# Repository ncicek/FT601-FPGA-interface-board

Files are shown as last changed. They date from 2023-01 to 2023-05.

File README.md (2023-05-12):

# FTDI FT601 breakout board

A PCB for interfacing FT601 with Lattice MachXO3 Starter Board.
Examples of C driver and Python driver can be found in driver folder.
Verilog and cocotb sims are in fpga folder.

# PCB:
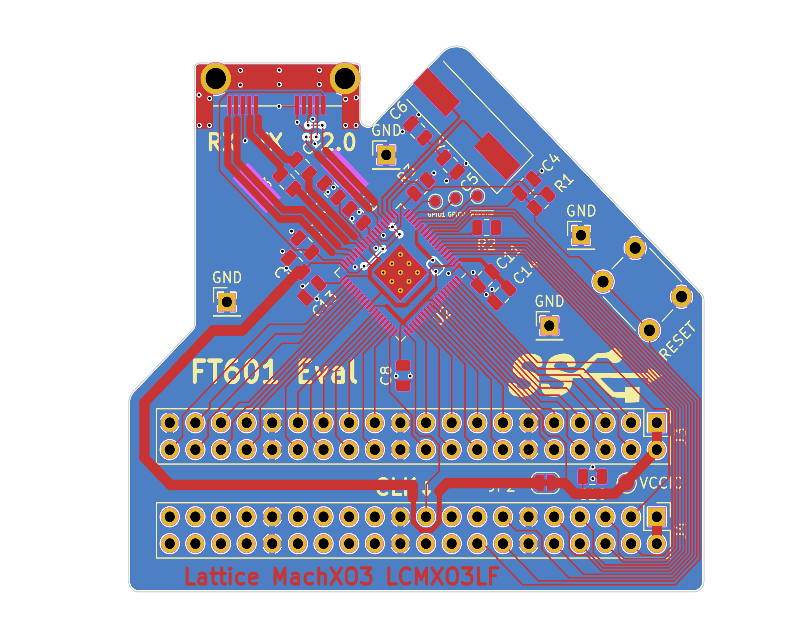
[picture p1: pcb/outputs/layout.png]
Photo of the ft601 layout

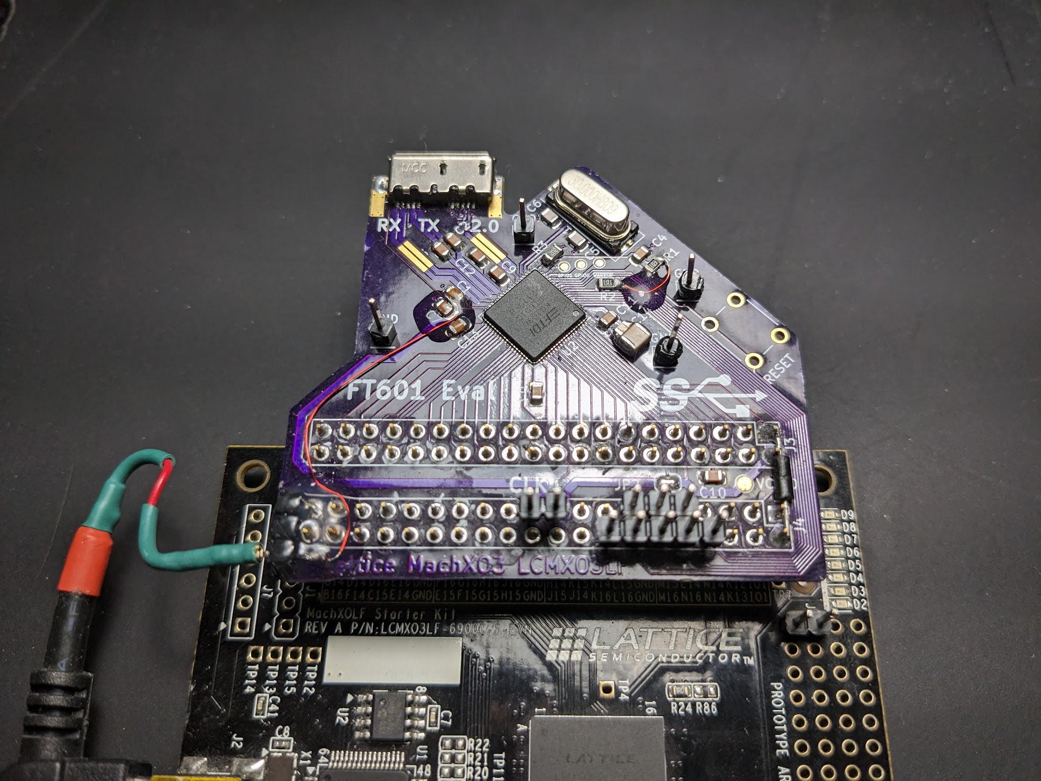
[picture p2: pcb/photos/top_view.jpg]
Photo of the ft601 board


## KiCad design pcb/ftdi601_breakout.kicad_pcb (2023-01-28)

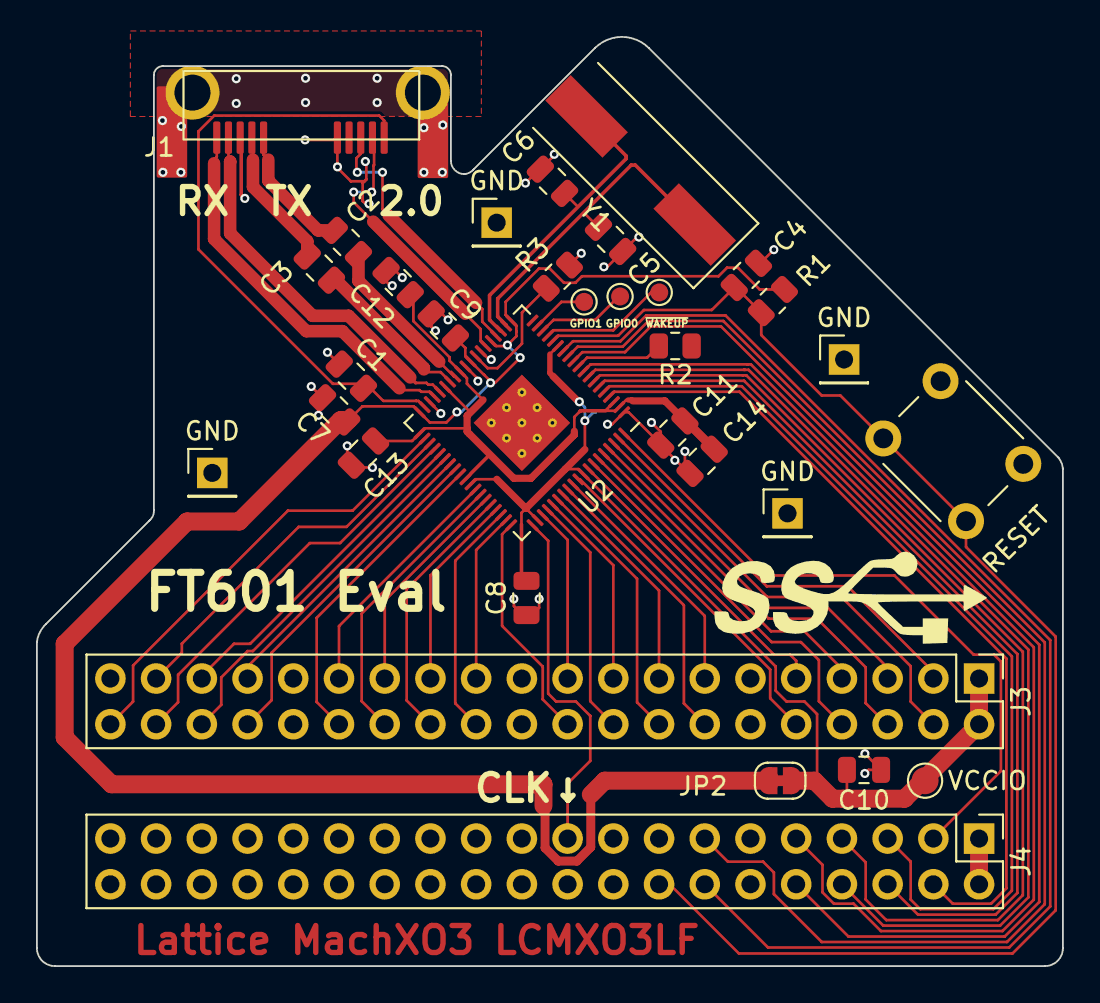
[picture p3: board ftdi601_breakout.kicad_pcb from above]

Board: 2 copper layers, 57.0 x 51.6 mm, 32 parts (1 on the bottom side), 63 nets.

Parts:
C1, C2, C3, C4, C7, C8, C9, C10, C11, C12, C13, C15: 0.1u; C_0805_2012Metric
C5, C6: 10p; C_0805_2012Metric
C14: 4.7u; C_0805_2012Metric
GND: TestPoint; PinHeader_1x01_P2.54mm_Vertical
GND#2, GND#3, GND#4: TestPoint; PinHeader_1x01_P2.54mm_Vertical
GPIO0, GPIO1: TestPoint; TestPoint_Pad_D1.0mm
J1: USB3_B; usb_microb_3.0
J3: J3 - BANK0; PinHeader_2x20_P2.54mm_Vertical
J4: J4 - BANK1; PinHeader_2x20_P2.54mm_Vertical
JP2: SolderJumper_2_Bridged; SolderJumper-2_P1.3mm_Bridged_RoundedPad1.0x1.5mm
R1, R2: 10k; R_0805_2012Metric
R3: 1.6k; R_0805_2012Metric
RESET: SW_Push; SW_PUSH_6mm
U2: FT601Q-B-T; QFN-76-1EP_9x9mm_P0.4mm_EP3.8x3.8mm_ThermalVias
VCCIO: TestPoint; TestPoint_Pad_D1.5mm
Y1: 30MHz CX3225SB30000H0FLJCC; Crystal_SMD_HC49-SD

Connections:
+1V0: C11.2, C12.2, C13.2, C14.2, U2.2 (AVDD), U2.3 (VD10), U2.30 (VD10), U2.33 (VD10), U2.39 (DV10), U2.48 (VD10)
+3V3: C7.2, C9.2, JP2.2 (B), R1.2, R2.2, U2.20 (VCC33), U2.24 (VCC33), U2.28 (VDDA), U2.38 (VCC33)
+5V: C1.1, J1.1 (VBUS), U2.37 (VBUS)
/BE_0: J4.4, U2.4 (BE_0)
/BE_1: J4.5, U2.5 (BE_1)
/BE_2: J4.6, U2.6 (BE_2)
/BE_3: J4.7, U2.7 (BE_3)
/D+: J1.3 (D+), U2.23 (DP)
/D-: J1.2 (D-), U2.25 (DM)
/DATA_0: J3.40, U2.40 (DATA_0)
/DATA_1: J3.37, U2.41 (DATA_1)
/DATA_2: J3.38, U2.42 (DATA_2)
/DATA_3: J3.35, U2.43 (DATA_3)
/DATA_4: J3.36, U2.44 (DATA_4)
/DATA_5: J3.33, U2.45 (DATA_5)
/DATA_6: J3.34, U2.46 (DATA_6)
/DATA_7: J3.30, U2.47 (DATA_7)
/DATA_8: J3.29, U2.50 (DATA_8)
/DATA_9: J3.28, U2.51 (DATA_9)
/DATA_10: J3.27, U2.52 (DATA_10)
/DATA_11: J3.26, U2.53 (DATA_11)
/DATA_12: J3.25, U2.54 (DATA_12)
/DATA_13: J3.24, U2.55 (DATA_13)
/DATA_14: J3.23, U2.56 (DATA_14)
/DATA_15: J3.20, U2.57 (DATA_15)
/DATA_16: J3.19, U2.60 (DATA_16)
/DATA_17: J3.18, U2.61 (DATA_17)
/DATA_18: J3.17, U2.62 (DATA_18)
/DATA_19: J3.16, U2.63 (DATA_19)
/DATA_20: J3.15, U2.64 (DATA_20)
/DATA_21: J3.14, U2.65 (DATA_21)
/DATA_22: J3.13, U2.66 (DATA_22)
/DATA_23: J3.10, U2.67 (DATA_23)
/DATA_24: J3.9, U2.69 (DATA_24)
/DATA_25: J3.8, U2.70 (DATA_25)
/DATA_26: J3.7, U2.71 (DATA_26)
/DATA_27: J3.6, U2.72 (DATA_27)
/DATA_28: J3.5, U2.73 (DATA_28)
/DATA_29: J3.4, U2.74 (DATA_29)
/DATA_30: J3.3, U2.75 (DATA_30)
/DATA_31: J4.3, U2.76 (DATA_31)
/FTDI_FIFO_CLK_OUT: J4.19, U2.58 (CLK)
/GPIO0: GPIO0.1, U2.17 (GPIO0)
/GPIO1: GPIO1.1, U2.18 (GPIO1)
/USB_RX+: J1.9 (SSRX+), U2.35 (RIDP)
/USB_RX-: J1.8 (SSRX-), U2.34 (RIDN)
/USB_TX+: C3.1, U2.32 (T0DP)
/USB_TX-: C2.1, U2.31 (T0DN)
/USB_TX_cap+: C3.2, J1.6 (SSTX+)
/USB_TX_cap-: C2.2, J1.5 (SSTX-)
/VCCIO0: C8.2, C10.2, C15.2, J3.1, J3.2, JP2.1 (A), U2.14 (VCCIO), U2.49 (VCCIO), U2.59 (VCCIO), U2.68 (VCCIO), VCCIO.1
/VCCIO1: J4.1, J4.2
/XTAL_N: C6.1, U2.22 (XO), Y1.2
/XTAL_P: C5.1, U2.21 (XI), Y1.1
/~OE: J4.14, U2.13 (OE_N)
/~RD: J4.13, U2.12 (RD_N)
/~RESET: C4.1, J4.16, R1.1, RESET.2, U2.15 (RESET_N)
/~RXF: J4.9, U2.9 (RXF_N)
/~TXE: J4.8, U2.8 (TXE_N)
/~WR: J4.10, U2.11 (WR_N)
GND: C1.2, C4.2, C5.2, C6.2, C7.1, C8.1, C9.1, C10.1, C11.1, C12.1, C13.1, C14.1, C15.1, GND.1, GND#2.1, GND#3.1, GND#4.1, J1.4 (GND), J1.7 (DRAIN), J1.10 (SHIELD), J3.11, J3.12, J3.21, J3.22, J3.31, J3.32, J3.39, J4.11, J4.12, J4.21, J4.22, J4.31, J4.32, R3.2, RESET.1, U2.1 (GND), U2.26 (GND), U2.29 (GND), U2.36 (GND), U2.77 (EXP)
unnamed: R2.1, U2.10 (SIWU_N)
unnamed: R3.1, U2.27 (RREF)

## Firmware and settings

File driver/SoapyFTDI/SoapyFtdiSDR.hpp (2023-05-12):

#include <vector>
#include <mutex>
#include <chrono>
#include <atomic>
#include <condition_variable>
#include <SoapySDR/Device.hpp>
#include <SoapySDR/Logger.hpp>
#include <SoapySDR/Types.hpp>
#include <SoapySDR/Formats.hpp>
#include <SoapySDR/ConverterRegistry.hpp>
#include "ftd3xx.h"

#define DEFAULT_BUFFER_LENGTH 256 //number of 
#define DEFAULT_NUM_BUFFERS 1024 //number of entries in ring buffer
#define BYTES_PER_SAMPLE 2
#define BYTES_PER_FLOAT (sizeof(float)/sizeof(uint8_t))

#define REG_ADDR_MODE 1
#define MODE_STREAM 1
#define REG_WRITE 1

#define NUM_DWORDS 1073741808 //30 bits

typedef enum rtlsdrRXFormat
{
    RTL_RX_FORMAT_FLOAT32, RTL_RX_FORMAT_INT16, RTL_RX_FORMAT_INT8
} rtlsdrRXFormat;

typedef struct circular_buffer
{
	void *buffer;     // data buffer
	void *buffer_end; // end of data buffer
	size_t capacity;  // maximum number of items in the buffer
	size_t count;     // number of items in the buffer
	size_t sz;        // size of each item in the buffer
	void *head;       // pointer to head
	void *tail;       // pointer to tail
} circular_buffer;

/*
#ifndef C_CODE_H
#define C_CODE_H

extern "C" {
	uint8_t *ftdi_buffer;
	circular_buffer cb;
}

#endif*/


class SoapyFtdiSDR : public SoapySDR::Device{

	public:
		SoapyFtdiSDR( const SoapySDR::Kwargs & args );
		~SoapyFtdiSDR();

		/*******************************************************************
		 * Identification API
		 ******************************************************************/

		std::string getDriverKey( void ) const;


		std::string getHardwareKey( void ) const;


		SoapySDR::Kwargs getHardwareInfo( void ) const;


		/*******************************************************************
		 * Channels API
		 ******************************************************************/

		size_t getNumChannels( const int ) const;


		//bool getFullDuplex( const int direction, const size_t channel ) const;

		/*******************************************************************
		 * Stream API
		 ******************************************************************/

		std::vector<std::string> getStreamFormats(const int direction, const size_t channel) const;

		std::string getNativeStreamFormat(const int direction, const size_t channel, double &fullScale) const;

		SoapySDR::ArgInfoList getStreamArgsInfo(const int direction, const size_t channel) const;

		SoapySDR::Stream *setupStream(
				const int direction,
				const std::string &format,
				const std::vector<size_t> &channels = std::vector<size_t>(),
				const SoapySDR::Kwargs &args = SoapySDR::Kwargs() );

		void closeStream( SoapySDR::Stream *stream );

		//size_t getStreamMTU( SoapySDR::Stream *stream ) const;

		int activateStream(
				SoapySDR::Stream *stream,
				const int flags = 0,
				const long long timeNs = 0,
				const size_t numElems = 0 );

		int deactivateStream(
				SoapySDR::Stream *stream,
				const int flags = 0,
				const long long timeNs = 0 );

		int readStream(
				SoapySDR::Stream *stream,
				void * const *buffs,
				const size_t numElems,
				int &flags,
				long long &timeNs,
				const long timeoutUs = 100000 );

		int readStreamStatus(
				SoapySDR::Stream *stream,
				size_t &chanMask,
				int &flags,
				long long &timeNs,
				const long timeoutUs
				);

		/*******************************************************************
		 * Settings API
		 ******************************************************************/

		SoapySDR::ArgInfoList getSettingInfo(void) const;


		void writeSetting(const std::string &key, const std::string &value);


		std::string readSetting(const std::string &key) const;


		/*******************************************************************
		 * Sample Rate API
		 ******************************************************************/

		void setSampleRate( const int direction, const size_t channel, const double rate );


		double getSampleRate( const int direction, const size_t channel ) const;


		std::vector<double> listSampleRates( const int direction, const size_t channel ) const;


		void setBandwidth( const int direction, const size_t channel, const double bw );


		double getBandwidth( const int direction, const size_t channel ) const;


		std::vector<double> listBandwidths( const int direction, const size_t channel ) const;

		//SoapySDR::RangeList getSampleRateRange(const int direction, const size_t channel) const;

	private:
        FT_HANDLE dev;

		//cached settings
		rtlsdrRXFormat rxFormat;
		uint32_t sampleRate, centerFrequency, bandwidth;
		int ppm, directSamplingMode;
		size_t numBuffers, bufferLength, asyncBuffs;

		bool iqSwap, gainMode, offsetMode, digitalAGC, testMode, biasTee;


		

	public:
		//async api usage
		void rx_async_operation(void);
		void rx_callback(unsigned char *buf, uint32_t len);

		signed char *_currentBuff;
		std::atomic<bool> _overflowEvent;
		size_t _currentHandle;
		size_t bufferedElems;
		size_t bufferType;
		std::atomic<bool> resetBuffer;
};

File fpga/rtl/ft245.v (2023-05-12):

module ft245_transmitter (i_reset,
            i_ftdi_clk, i_ftdi_txe_n, i_ftdi_rxf_n,
            io_ftdi_data, io_ftdi_be, o_ftdi_oe_n, o_ftdi_wr_n, o_ftdi_rd_n, o_serial_out, o_leds_n, o_ftdi_reset_n, o_fsm);
    input wire i_ftdi_clk, i_reset;
    input wire i_ftdi_txe_n, i_ftdi_rxf_n;
    inout wire [3:0] io_ftdi_be;
    inout wire [31:0] io_ftdi_data;
    output reg o_ftdi_wr_n = 1;
	output wire o_ftdi_oe_n;
	output reg o_ftdi_rd_n = 1;
	output wire [7:0] o_leds_n;
	output reg o_serial_out;
	output wire o_ftdi_reset_n;
	output wire [3:0] o_fsm;

	localparam STATE_IDLE = 0;
	localparam STATE_TRANSMIT_1 = 1;
	localparam STATE_ADDRESS_READ = 2;
	localparam STATE_DATA_READ = 3;
	localparam STATE_DECODE_CMD = 4;
	localparam STATE_TRANSMIT_2 = 5;
	localparam STATE_TRANSMIT_3 = 6;


	assign io_ftdi_be = 4'b1111;
	assign o_ftdi_reset_n = !i_reset;
	
	wire fifo_full; //we are dropping data when this is high
	wire [31:0] fifo_output_data;
	
	reg [31:0] data = 0;
	always @(posedge i_ftdi_clk or posedge i_reset) begin
		if (i_reset) begin
			data <= 0;
		end else begin
			if (!fifo_full) begin
				data <= data + 1;
			end
		end
	end
	/*sfifo 
	#(
		.BW                (32                ),
		.LGFLEN            (4          )
	)
	u_sfifo(
		.i_clk                (i_ftdi_clk                ),
		.i_reset              (i_reset              ),
		.i_wr                 (!fifo_full),
		.i_data               (data               ),
		.o_full               (fifo_full               ),
		.o_fill               (               ),
		.i_rd                 ((!i_ftdi_txe_n) && (fsm == STATE_TRANSMIT || fsm == STATE_TRANSMIT_2)),
		.o_data               (fifo_output_data),
		.o_empty              (              )
	);*/

	assign fifo_output_data[31:0] = data[31:0];
	assign fifo_full = 0;

	assign o_ftdi_oe_n = o_ftdi_rd_n; //allow slave to drive io_ftdi_data bus when we are reading
	assign io_ftdi_data = o_ftdi_oe_n ? fifo_output_data : 32'bZ;
	
	//Register definitions
	localparam REG_ADDR_TEST = 0;
	localparam REG_ADDR_MODE = 1;

	localparam REG_READ = 0;
	localparam REG_WRITE = 1;

	localparam MODE_STREAM = 1;
	localparam MODE_IDLE = 0;

	reg[31:0] reg_test = 32'hDEADBEEF; //read only test reg
	reg[31:0] reg_mode = MODE_IDLE << 31;

	wire [7:0] o_leds;
	assign o_leds = data[23:16];
	assign o_leds_n = ~o_leds;

	reg [3:0] register_address;
	reg [31:0] register_data;
	reg register_access = REG_READ;

	reg [30:0] dwords_to_transmit;

	//Sequence: send two dwords to bus master
	//DWORD0[31] = READ/WRITE (0/1)
	//DWORD0[3:0] = ADDRESS
	//DWORD1[31:0] = DATA

	reg [3:0] fsm = STATE_IDLE;
	assign o_fsm = fsm;
	always @(posedge i_ftdi_clk or posedge i_reset) begin //reset stops the ftdi_clk so need be sensitive to both edges
		if (i_reset) begin
			fsm <= STATE_IDLE;
			reg_mode <= MODE_IDLE << 31;
		end else begin
			case (fsm)
				STATE_IDLE: begin //Listen state, wait for a command from host
					if (i_ftdi_rxf_n == 0) begin //got data from host, go handle that
						fsm <= STATE_ADDRESS_READ;
					end else if (reg_mode[31] == MODE_STREAM) begin //stream mode enabled
						fsm <= STATE_TRANSMIT_1;
					end
				end

				STATE_TRANSMIT_1: begin //dumping data to the host
					dwords_to_transmit <= 0;
					fsm <= STATE_TRANSMIT_2;
				end

				STATE_TRANSMIT_2: begin //dumping data to the host
					if (dwords_to_transmit >= reg_mode[29:0]) begin
						fsm <= STATE_IDLE;
						reg_mode[31] <= MODE_IDLE; //reset the transmission after a transmit dump
					end else begin
						fsm <= STATE_TRANSMIT_3;
					end
				end

				STATE_TRANSMIT_3: begin //dumping data to the host step 2 of pipeline
					if (i_ftdi_txe_n == 0) begin //when tx buffer is has space, we transfer
						dwords_to_transmit <= dwords_to_transmit + 2;
					end
					fsm <= STATE_TRANSMIT_2;
				end


				STATE_ADDRESS_READ: begin //read first dword which is address
					register_address <= io_ftdi_data[3:0];
					register_access <= io_ftdi_data[31];
					fsm <= STATE_DATA_READ;
				end

				STATE_DATA_READ: begin //read second dword which is data
					register_data <= io_ftdi_data;
					fsm <= STATE_DECODE_CMD;
				end

				STATE_DECODE_CMD: begin
					if (register_access == REG_WRITE) begin
						if (register_address == REG_ADDR_TEST) begin
							//reg_test <= register_data;
						end else if (register_address == REG_ADDR_MODE) begin
							reg_mode <= register_data;
						end
					end
					if (i_ftdi_rxf_n == 1) begin //wait for rx buffer to flush before returning to idle
						fsm <= STATE_IDLE;
					end
				end

				default: begin
					fsm <= STATE_IDLE;
				end
			endcase
		end
	end


	always @(*) begin
		case (fsm)
			STATE_IDLE: begin
				o_ftdi_rd_n = 1;
				o_ftdi_wr_n = 1;
			end
			
			STATE_TRANSMIT_1: begin
				o_ftdi_rd_n = 1;
				o_ftdi_wr_n = 0;
			end

			STATE_TRANSMIT_2: begin
				o_ftdi_rd_n = 1;
				o_ftdi_wr_n = 0;
			end

			STATE_TRANSMIT_3: begin
				o_ftdi_rd_n = 1;
				o_ftdi_wr_n = 0;
			end

			STATE_ADDRESS_READ: begin
				o_ftdi_rd_n = 0;
				o_ftdi_wr_n = 1;
			end

			STATE_DATA_READ: begin
				o_ftdi_rd_n = 0;
				o_ftdi_wr_n = 1;
			end

			STATE_DECODE_CMD: begin
				o_ftdi_rd_n = 1;
				o_ftdi_wr_n = 1;
			end

			default: begin
				o_ftdi_rd_n = 1;
				o_ftdi_wr_n = 1;
			end
		endcase
	end

	`ifdef COCOTB_SIM
		initial begin
		$dumpfile ("ft245_transmitter.vcd");
		$dumpvars (0, ft245_transmitter);
		#1;
		end
	`endif

endmodule
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
